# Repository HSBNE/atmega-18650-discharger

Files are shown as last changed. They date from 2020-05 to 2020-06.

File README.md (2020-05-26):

# atmega-18650-discharger

An arduino. atmega1280/2560 18650 battery discharger and capacity tester supporting 30 concurrent battery's being discharged, simple mobile phone interface using wifi, OSC protocol and UDP messages to off-the-shelf phone application called 'Touch OSC'. 

Discharges what is assumed ot be a fully-charged 18650 down till a given threshold, then stops the discharging, measuring the actual discharge profile over time and tells user the measure capacity at hte end of the discharge cycle.

Original code by @davidbuzz, working with esp8266/esp12 as wifi interface and master controller and 2x Arduino Mega 2560 slaves.

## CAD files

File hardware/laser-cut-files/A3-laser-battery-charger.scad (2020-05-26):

//page size
w=297;
h=420;

// battery "single" size ( in this case it's a pair ) 
batt_w = 18.5;
batt_h = 70;

// frame outer dimension
perimeter = 11;

// inner-spacing
wide_inner = 10;
thin_inner = 10;

// batteries in a stack = 20
battstack = 1;

// holeoffsets
holeoffset1 = 6;
holeoffset2 = 16;


//echo((h-(batt_h*battstack))/2);

difference(){ 
square([w,h],centre=false); // A3 sheet to start on.

// three rows out from centre.
for (i = [-140,-20,100]){ 

translate ( [0,i,0] ) {     
offset1 = perimeter;
translate([offset1,(h-(batt_h*battstack))/2,0]) square([batt_w,batt_h*battstack],centre=false);
translate([offset1+6,(h-(batt_h*battstack))/2-3,0]) square([6,1],centre=false);
translate([offset1+6,(h-(batt_h*battstack))/2-5,0]) square([6,1],centre=false);
translate([offset1+6,(h-(batt_h*battstack))/2+batt_h+3,0]) square([6,1],centre=false);
translate([offset1+6,(h-(batt_h*battstack))/2+batt_h+5,0]) square([6,1],centre=false);

offset2 = offset1+batt_w+wide_inner;
translate([offset2,(h-(batt_h*battstack))/2,0]) square([batt_w,batt_h*battstack],centre=false);
translate([offset2+6,(h-(batt_h*battstack))/2-3,0]) square([6,1],centre=false);
translate([offset2+6,(h-(batt_h*battstack))/2-5,0]) square([6,1],centre=false);
translate([offset2+6,(h-(batt_h*battstack))/2+batt_h+3,0]) square([6,1],centre=false);
translate([offset2+6,(h-(batt_h*battstack))/2+batt_h+5,0]) square([6,1],centre=false);
    
offset3 = offset2+batt_w+thin_inner;
translate([offset3,(h-(batt_h*battstack))/2,0]) square([batt_w,batt_h*battstack],centre=false);
translate([offset3+6,(h-(batt_h*battstack))/2-3,0]) square([6,1],centre=false);
translate([offset3+6,(h-(batt_h*battstack))/2-5,0]) square([6,1],centre=false);
translate([offset3+6,(h-(batt_h*battstack))/2+batt_h+3,0]) square([6,1],centre=false);
translate([offset3+6,(h-(batt_h*battstack))/2+batt_h+5,0]) square([6,1],centre=false);
    
offset4 = offset3+batt_w+wide_inner;
translate([offset4,(h-(batt_h*battstack))/2,0]) square([batt_w,batt_h*battstack],centre=false);
translate([offset4+6,(h-(batt_h*battstack))/2-3,0]) square([6,1],centre=false);
translate([offset4+6,(h-(batt_h*battstack))/2-5,0]) square([6,1],centre=false);
translate([offset4+6,(h-(batt_h*battstack))/2+batt_h+3,0]) square([6,1],centre=false);
translate([offset4+6,(h-(batt_h*battstack))/2+batt_h+5,0]) square([6,1],centre=false);
    
offset5 = offset4+batt_w+thin_inner;
translate([offset5,(h-(batt_h*battstack))/2,0]) square([batt_w,batt_h*battstack],centre=false);
translate([offset5+6,(h-(batt_h*battstack))/2-3,0]) square([6,1],centre=false);
translate([offset5+6,(h-(batt_h*battstack))/2-5,0]) square([6,1],centre=false);
translate([offset5+6,(h-(batt_h*battstack))/2+batt_h+3,0]) square([6,1],centre=false);
translate([offset5+6,(h-(batt_h*battstack))/2+batt_h+5,0]) square([6,1],centre=false);

offset6 = offset5+batt_w+wide_inner;
translate([offset6,(h-(batt_h*battstack))/2,0]) square([batt_w,batt_h*battstack],centre=false);
translate([offset6+6,(h-(batt_h*battstack))/2-3,0]) square([6,1],centre=false);
translate([offset6+6,(h-(batt_h*battstack))/2-5,0]) square([6,1],centre=false);
translate([offset6+6,(h-(batt_h*battstack))/2+batt_h+3,0]) square([6,1],centre=false);
translate([offset6+6,(h-(batt_h*battstack))/2+batt_h+5,0]) square([6,1],centre=false);

offset7 = offset6+batt_w+thin_inner;
translate([offset7,(h-(batt_h*battstack))/2,0]) square([batt_w,batt_h*battstack],centre=false);
translate([offset7+6,(h-(batt_h*battstack))/2-3,0]) square([6,1],centre=false);
translate([offset7+6,(h-(batt_h*battstack))/2-5,0]) square([6,1],centre=false);
translate([offset7+6,(h-(batt_h*battstack))/2+batt_h+3,0]) square([6,1],centre=false);
translate([offset7+6,(h-(batt_h*battstack))/2+batt_h+5,0]) square([6,1],centre=false);

offset8 = offset7+batt_w+wide_inner;
translate([offset8,(h-(batt_h*battstack))/2,0]) square([batt_w,batt_h*battstack],centre=false);
translate([offset8+6,(h-(batt_h*battstack))/2-3,0]) square([6,1],centre=false);
translate([offset8+6,(h-(batt_h*battstack))/2-5,0]) square([6,1],centre=false);
translate([offset8+6,(h-(batt_h*battstack))/2+batt_h+3,0]) square([6,1],centre=false);
translate([offset8+6,(h-(batt_h*battstack))/2+batt_h+5,0]) square([6,1],centre=false);

offset9 = offset8+batt_w+thin_inner;
translate([offset9,(h-(batt_h*battstack))/2,0]) square([batt_w,batt_h*battstack],centre=false);
translate([offset9+6,(h-(batt_h*battstack))/2-3,0]) square([6,1],centre=false);
translate([offset9+6,(h-(batt_h*battstack))/2-5,0]) square([6,1],centre=false);
translate([offset9+6,(h-(batt_h*battstack))/2+batt_h+3,0]) square([6,1],centre=false);
translate([offset9+6,(h-(batt_h*battstack))/2+batt_h+5,0]) square([6,1],centre=false);

offset10 = offset9+batt_w+thin_inner;
translate([offset10,(h-(batt_h*battstack))/2,0]) square([batt_w,batt_h*battstack],centre=false);
translate([offset10+6,(h-(batt_h*battstack))/2-3,0]) square([6,1],centre=false);
translate([offset10+6,(h-(batt_h*battstack))/2-5,0]) square([6,1],centre=false);
translate([offset10+6,(h-(batt_h*battstack))/2+batt_h+3,0]) square([6,1],centre=false);
translate([offset10+6,(h-(batt_h*battstack))/2+batt_h+5,0]) square([6,1],centre=false);

}

}



//bus holes
//translate([offset2-wide_inner/2,holeoffset1,0]) circle(d=6.5);
//translate([offset2-wide_inner/2,h-holeoffset1,0]) circle(d=6.5);
//translate([offset4-wide_inner/2,holeoffset1,0]) circle(d=6.5);
//translate([offset4-wide_inner/2,h-holeoffset1,0]) circle(d=6.5);
//translate([offset6-wide_inner/2,holeoffset1,0]) circle(d=6.5);
//translate([offset6-wide_inner/2,h-holeoffset1,0]) circle(d=6.5);

// mount holes
translate([w*1/32,holeoffset2,0]) circle(d=6.5);
translate([w*11/32,holeoffset2,0]) circle(d=6.5);
translate([w*21/32,holeoffset2,0]) circle(d=6.5);
translate([w*31/32,holeoffset2,0]) circle(d=6.5);

translate([w*1/32,h-holeoffset2,0]) circle(d=6.5);
translate([w*11/32,h-holeoffset2,0]) circle(d=6.5);
translate([w*21/32,h-holeoffset2,0]) circle(d=6.5);
translate([w*31/32,h-holeoffset2,0]) circle(d=6.5);

translate([w*1/32,140,0]) circle(d=6.5);
translate([w*11/32,140,0]) circle(d=6.5);
translate([w*21/32,140,0]) circle(d=6.5);
translate([w*31/32,140,0]) circle(d=6.5);

translate([w*1/32,260,0]) circle(d=6.5);
translate([w*11/32,260,0]) circle(d=6.5);
translate([w*21/32,260,0]) circle(d=6.5);
translate([w*31/32,260,0]) circle(d=6.5);

//optional ruler markes on cutouts. 
    
} 

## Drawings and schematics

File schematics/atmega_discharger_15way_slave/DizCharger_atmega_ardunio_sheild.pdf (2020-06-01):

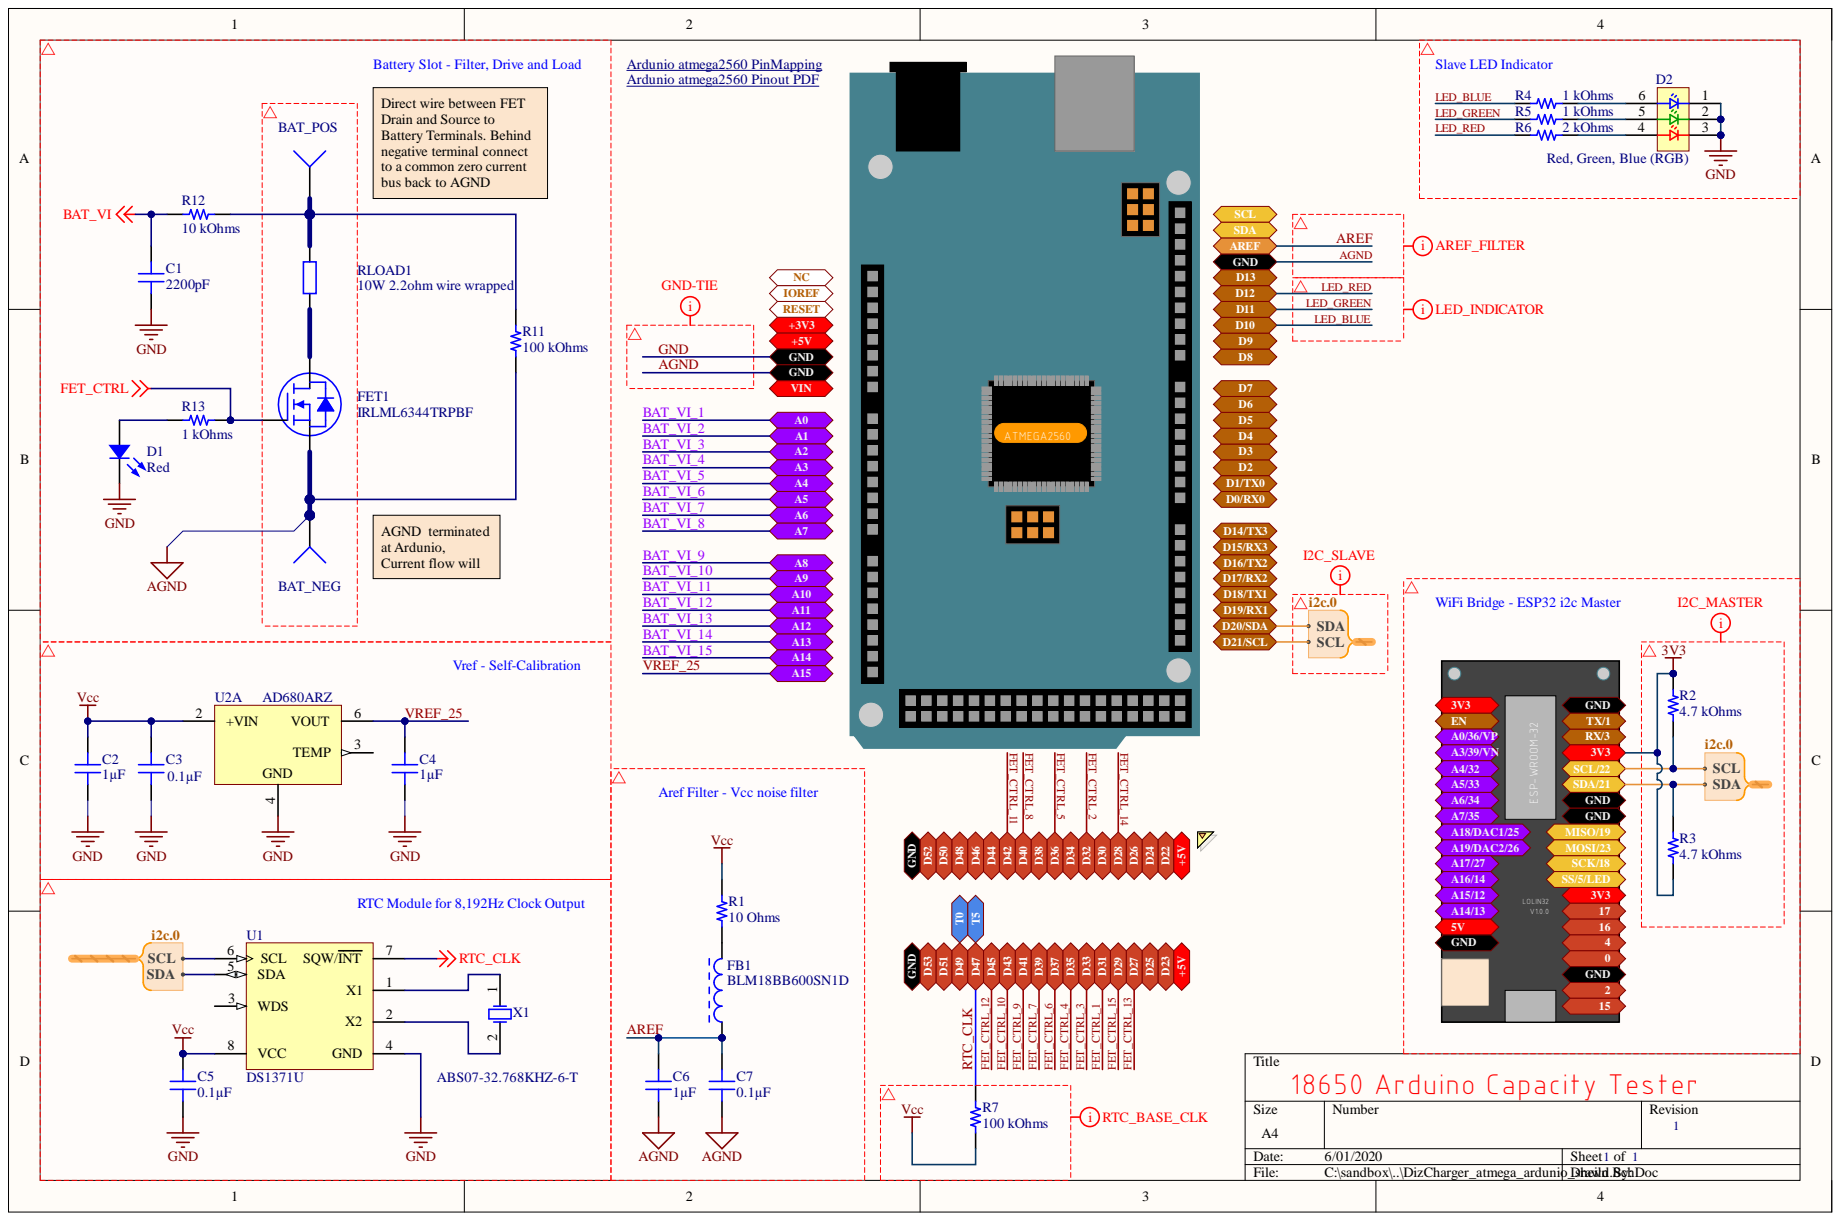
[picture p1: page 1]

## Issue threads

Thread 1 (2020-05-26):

Charge end-state-wait and state-discharge triggering incorrectly

ArakniD, 2020-05-26:
The end state should be maintained even when the voltage floats back upwards after a discharge. The discharge should not cycle again until voltage is removed entirely and float voltage goes above 4.130v

The start charge sequence should require a OCV above 4.130v before initiating a new discharge cycle.

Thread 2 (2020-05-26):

ADC Vref need a configuration #define for an external 4.5v Aref connection in place of A15 usage

ArakniD, 2020-05-26:
New configuration for the ADC using a 4.5v Aref connection instead of self-calibrating 2.5v on A15.

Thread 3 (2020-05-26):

WiFi Bridge needs an external switch to enable AP or Client mode

ArakniD, 2020-05-26:
Having an external switch allows taking the discharge mobile and in-field testing.

The WiFi AP mode needs to transmit data to ALL connected clients.

Implement the transmission of the multi-dial socket-loss from the esp32 code, mirror whats in node-red.

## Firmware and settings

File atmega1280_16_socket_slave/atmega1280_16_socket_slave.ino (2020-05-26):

// with I2C slave support!  see other sketch called esp8266_wifi_bridge.ino for master, with OSC etc. 
#include <Wire.h>

// 1 -> whatever
#define DEVICEID 2
// I2C device IDs start at 8 and go up.
#define I2C_DEVICEID DEVICEID+8

// earlier code had only 3 on Nano, etc.
#define POSITIONS 16

int DEBUG = 1;

// battery constant characteristics
float LiMinThreshold = 2700; //3900; //2700; // 2700 = Lithium Minimal Voltage for load removal, 3900 = minimum needed for re-charger to kick in.
float LiMaxThreshold = 4220; // Lithium Max Voltage for load removal
int power_resistor_value = 2.2; // needs to be in the range 1.8-2.5 ohms. best is 2 or 2.2 ohms, typically approx 10W  ( eg, 2x1ohm 5w in series will do , or a 2.2ohm 10W) 

// 5V NANO ADC to mV VOLTAGE FACTOR is 4.887
// 5V MEGA1280 ADC to mV VOLTAGE FACTOR is 13.53
#define ADC 4.887
//#define ADC 130.1

int i;

//16 way! - the most important thing is 16 available ADCs, and 16 digital IO for mosfets, as a bonus, we have 16 digital io for LEDs too. and still spares after that. :
// constants
unsigned int sensor1Pins[POSITIONS] = { A0,A1,A2,A3,A4,A5,A6,A7,A8,A9,A10,A11,A12,A13,A14,A15 };
//int sensor2Pins[] = { 0, 4, 5 }; // we don't have 3 separate analog pins avail here because we use I2C on A4 and A5.
unsigned int ledPins[POSITIONS] = { 22,23,24,25,26,27,28,29,30,31,32,33,34,35,36,37 };
unsigned int FETPins[POSITIONS] = { 4,5,6,7,8,9,10,11,12,13,14,15,16,17,18,19 };  // don't use 20 or 21 for IO, as they are for I2C comms on a 2560.
unsigned int SPKPins[POSITIONS] = {  3, 3 , 3,3,3,3,3,3,3,3,3,3,3,3,3,3 };
// variables
unsigned int sensor1Values[POSITIONS] = { 0 , 0 ,0 ,0 ,0 ,0 ,0 ,0 ,0 ,0 ,0 ,0 ,0 ,0 ,0 , 0 };
//int sensor2Values[] = { 0 , 0 , 0 };
unsigned int BatVoltages[POSITIONS] = { 5000, 5000,5000,5000,5000,5000,5000,5000,5000,5000,5000,5000,5000,5000,5000, 5000};
unsigned int FetVoltages[POSITIONS] = { 40,40,40,40,40,40,40,40,40,40,40,40,40,40,40, 40}; // with enough spare ADCs we can calculate these, but for now we know its close to 40mV most of the time
unsigned int MilliAmps[POSITIONS] = { 0, 0,0,0,0,0,0,0,0,0,0,0,0,0,0, 0};    // these ints are 16bit values
unsigned long TotalCurrents[POSITIONS] = { 0, 0, 0, 0, 0, 0, 0, 0, 0, 0, 0, 0, 0, 0, 0, 0};   // LONG, as we go over 65k

boolean batterypresents[POSITIONS] = { false, false,false,false,false,false,false,false,false,false,false,false,false,false,false, false};
boolean dones[POSITIONS] =           { false, false,false,false,false,false,false,false,false,false,false,false,false,false,false, false} ;
boolean ledstates[POSITIONS] =       { false, false,false,false,false,false,false,false,false,false,false,false,false,false,false, false} ;
unsigned long PrevMilliss[POSITIONS]  =      {0,0,0,0,0,0,0,0,0,0,0,0,0,0,0,0};
unsigned long MillisPasseds[POSITIONS] =     {0,0,0,0,0,0,0,0,0,0,0,0,0,0,0,0};
unsigned long time_since_starts[POSITIONS] = {0,0,0,0,0,0,0,0,0,0,0,0,0,0,0,0}; 
unsigned long time_ends[POSITIONS] =         {0,0,0,0,0,0,0,0,0,0,0,0,0,0,0,0}; 

// I2C packet...... 
typedef struct sensorData_t{
  byte stx;
  byte DeviceID;   // device ID.   
  byte batvoltage1_low;
  byte batvoltage1_hi;
  byte Running1;
  byte MilliAmps1_low;
  byte MilliAmps1_hi;
  byte TotalCurrents1_low;
  byte TotalCurrents1_hi;
  byte time_ends1_low;
  byte time_ends1_hi;
  byte etx;
};
#define PACKET_SIZE 12  // can NEVER exceeed 32, hardware limit.
//#define PACKET_SIZE sizeof(sensorData_t)

// as bytes.....
typedef union I2C_Packet_t{
sensorData_t sensor;
byte I2CPacket[sizeof(sensorData_t)];
};
I2C_Packet_t batteryinfo;


void shortbeep(int pos){
            digitalWrite(SPKPins[pos], HIGH);
            delay(1);
            digitalWrite(SPKPins[pos], LOW);
}

byte REQUESTEDPOS = 0x00;
void receiveEvent(int bytes)
{
  if(Wire.available() != 0)
  {
    for(int i = 0; i< bytes; i++)
    {
      REQUESTEDPOS = Wire.read();
      if (DEBUG > 0 ) Serial.print("Received: ");
      if (DEBUG > 0 ) Serial.print(REQUESTEDPOS, HEX);
      if (DEBUG > 0 ) Serial.print("\n");
    }
  }
}

// just like analogRead only it does 2 slow reads and makes sure they are within 10% of each other
int debouncedAnalogRead(int pin){ 
  int trydata[] = { 0,100 } ;
  //for(int _try = 0; _try < 2 ; _try++ ) { 
      trydata[0] = analogRead(pin);
   //delay(50);
      trydata[1] = analogRead(pin);
   //delay(50);
  //}
  // ADC values are out of 1024, so 10% is about 100
  while (abs(trydata[0]-trydata[1]) > 10 ) {
    //Serial.println("poor ADC value");
    //Serial.println(abs(trydata[0]-trydata[1]));
   delay(50);

      trydata[0] = analogRead(pin);
   //delay(50);
      trydata[1] = analogRead(pin);
   //delay(50);
    
//    Serial.println
  }
  return trydata[1]; // second try is probably better. 
}

// function that executes whenever data is requested by master
// this function is registered as an event, see setup()
void requestEvent() {

    if ((REQUESTEDPOS < 0) or ( REQUESTEDPOS > POSITIONS )) { REQUESTEDPOS = 0; } // if not given a decent offset, assume the first one.

    // turn human readable 1-based offset back to 0-based array offset:
    int __REQUESTEDPOS = REQUESTEDPOS-1;

    // fill the packet 
    batteryinfo.sensor.stx=2; // just becasue, we don't use this other than to tel that a packet is not all zeros
    batteryinfo.sensor.DeviceID=DEVICEID; // human-readable of DeviceID is passed back too.
    batteryinfo.sensor.batvoltage1_low = (byte)BatVoltages[__REQUESTEDPOS];
    batteryinfo.sensor.batvoltage1_hi = BatVoltages[__REQUESTEDPOS]  >> 8;
    batteryinfo.sensor.Running1= dones[__REQUESTEDPOS]?0:1;
    batteryinfo.sensor.MilliAmps1_low = (byte)MilliAmps[__REQUESTEDPOS];
    batteryinfo.sensor.MilliAmps1_hi = MilliAmps[__REQUESTEDPOS]  >> 8;
    batteryinfo.sensor.TotalCurrents1_low = (byte)(TotalCurrents[__REQUESTEDPOS]/1000);
    batteryinfo.sensor.TotalCurrents1_hi = (TotalCurrents[__REQUESTEDPOS]/1000)  >> 8;
    batteryinfo.sensor.time_ends1_low = (byte)time_ends[__REQUESTEDPOS];
    batteryinfo.sensor.time_ends1_hi = time_ends[__REQUESTEDPOS]  >> 8;
    batteryinfo.sensor.etx=REQUESTEDPOS; // pass back the human-readable of REQUESTEDPOS

    // send the packet.
    Wire.write(batteryinfo.I2CPacket, PACKET_SIZE);

  
}

void cycle_leds(){
  Serial.println("Cycling LEDs");

   for( int pos = 0 ; pos < POSITIONS ; pos++ ) { 
     digitalWrite(ledPins[pos], HIGH);   // turn the LED on (HIGH is the voltage level)
      delay(200);              // wait for a second
      digitalWrite(ledPins[pos], LOW);    // turn the LED off by making the voltage LOW
      delay(200);              // wait for a second
   }
  Serial.println("LEDs test done");
}

void setup() {
  
  Serial.begin(57600);// start serial port to send data during run to the PC
  Serial.println("Bat PWR Tester[Active]");  // Print a message to the //lcd.
  Serial.println("Detecting Bat .... please put one in now if not already...."); // print voltage value
  Serial.println("                        ");
  Serial.println(PACKET_SIZE);

  // init all the IO and pullups and lEDs etc. 
  for( int pos = 0 ; pos < POSITIONS ; pos++ ) { 
    
      pinMode(ledPins[pos], OUTPUT);//activation led and enable for FET
      pinMode(FETPins[pos], OUTPUT);//activation led and enable for FET
      pinMode(SPKPins[pos], OUTPUT);//activation led and enable for FET
   
      //elay(200);  //s[pos]
      digitalWrite(ledPins[pos], HIGH);   // set the LED on
      digitalWrite(FETPins[pos], HIGH);   // set the LED on
      digitalWrite(ledPins[pos], LOW);   // set the LED off
      digitalWrite(FETPins[pos], LOW);   // set the LED off

      // read ADC
      sensor1Values[pos] = debouncedAnalogRead(sensor1Pins[pos]);   // read the value from the sensor:
  
      // Detecting battery type
      BatVoltages[pos] = sensor1Values[pos]*ADC;
      
      Serial.print("\tDevice=");

      Serial.print(sensor1Values[pos]); // raw ADC 
      Serial.print("\t");
      
      Serial.print(pos+1); // print displayable position, starting from .1
      Serial.print("\t");
                 
      if (BatVoltages[pos] > LiMaxThreshold){
        Serial.print("Warning high-V! V > 4.5 \t");
        dones[pos] = true;
        batterypresents[pos] = true;
      }
    
      if (BatVoltages[pos] > LiMinThreshold){
        Serial.print("Type:Li-Ion Bat. \t");
        batterypresents[pos] = true;
       }
    
      if (BatVoltages[pos] < 2){
        Serial.print("Unknown or FLAT BATTERY V<2 \t");
        dones[pos] = true;
        batterypresents[pos] = false;
      }
      
      Serial.print("\tV=");
      Serial.print(sensor1Values[pos]*ADC); // print voltage value
      Serial.println("mV");

  PrevMilliss[pos]  = millis();
  time_since_starts[pos] = millis();

  } 

  cycle_leds(); // demo/tester

  // after all the GPIOs are init-ed to their correct state, we can start listening for wire transfers.   
  Wire.begin(I2C_DEVICEID);     // join i2c bus with an address above #8
  Wire.onReceive(receiveEvent); // for incoming data TO slave 
  Wire.onRequest(requestEvent); // register event to trigger outgoing data FROM slave


  //delay(1000);
  Serial.println("-------------------------------------------------------------");
  
  shortbeep(0);
}


void loop() {
      Serial.println("-------------------------------------------------------------");
            delay(1000);

    for( int pos = 0 ; pos < POSITIONS ; pos++ ) { 
  
          if (BatVoltages[pos] > LiMinThreshold && !dones[pos]) {
            digitalWrite(ledPins[pos], HIGH);   // set the LED on
            digitalWrite(FETPins[pos], HIGH);   // set the LED on
            sensor1Values[pos] = debouncedAnalogRead(sensor1Pins[pos]);   // read the value from the sensor:
            BatVoltages[pos] = (sensor1Values[pos]*ADC);
            //sensor2Values[pos] = analogRead(sensor2Pins[pos]);   // read the value from the FET:
            //FetVoltages[pos] = (sensor2Values[pos]*ADC);  // this is the way to calculate it if you don't use the default value

            Serial.print("\tDevice=");
            Serial.print(DEVICEID); // print voltage value
            Serial.print(".");
            Serial.print(pos+1); // print human readable starting from 1
            
 
            Serial.print("\t[RUNNING] BattmV=");
            Serial.print(BatVoltages[pos]); // print voltage value
            
   
            MilliAmps[pos] = (BatVoltages[pos]-FetVoltages[pos])/power_resistor_value; 
            if ( MilliAmps[pos] < 0 ) { MilliAmps[pos] = 0; } // dissallow neg values
            if ( MilliAmps[pos] > 32000 ) { MilliAmps[pos] = 0; } // dissallow neg values
            Serial.print("\tmilliAmps=");
            Serial.print(MilliAmps[pos]); // print value        
            
            TotalCurrents[pos]=TotalCurrents[pos]+MillisPasseds[pos]/1000*MilliAmps[pos]/3.6; 
            Serial.print("  \tI=");
            Serial.print(TotalCurrents[pos]/1000);
            Serial.print("mAH  ");

            MillisPasseds[pos] = millis()- PrevMilliss[pos] ;
            PrevMilliss[pos] = millis();
    
            Serial.print("\tSecs:");    // prints a tab
            time_ends[pos] = int((millis()-time_since_starts[pos])/1000);
            Serial.print(time_ends[pos]);
 
            Serial.print("\t FETmV=");
            Serial.print(FetVoltages[pos]); // print value
 
            Serial.println();
          }
          else
          {
            // if we've "finished" ( moving to the done state ) , beep once.
            if (dones[pos] == false ) {
              shortbeep(pos);
              //time_ends[pos] = int((millis()-time_since_starts[pos])/1000);
            }
            dones[pos]=true;

            
            digitalWrite(ledPins[pos], LOW);   // set the LED off - stop loading
            digitalWrite(FETPins[pos], LOW);   // set the LED off - stop loading

            Serial.print("\tDevice=");
            Serial.print(DEVICEID); // print voltage value
            Serial.print(".");
            Serial.print(pos+1); // print voltage value
            Serial.print("\t[ DONE  ] ");  // Print a message to the //lcd.
    
            sensor1Values[pos] = debouncedAnalogRead(sensor1Pins[pos]);   // read the value from the sensor:
            BatVoltages[pos] = (sensor1Values[pos]*ADC);
    
            Serial.print("BattmV=");
            Serial.print(BatVoltages[pos]); // print voltage value

            Serial.print("\tmilliAmps=");
            Serial.print(MilliAmps[pos]); // print value        
 
            Serial.print("  \tI=");
            Serial.print(TotalCurrents[pos]/1000);    
            Serial.print("mAH  ");

            Serial.print("\tSecs:");    // prints a tab
            Serial.print(time_ends[pos]);

  
            // if battery is still in holder, but we are done with it... flash LED of appropriate slot..
            if ( batterypresents[pos] ) { 
                  if ( ledstates[pos] == LOW ) { 
                      digitalWrite(ledPins[pos], HIGH);
                      ledstates[pos] = HIGH;
                  } else { 
                      digitalWrite(ledPins[pos], LOW);
                      ledstates[pos] = LOW; 
                  }
                  //delay(100);
            } 

            bool restarting = false;
            
            // if the battery voltage is suddenly LOWER than 1v, it was clearly taken OUT. 
            if (( batterypresents[pos] == true) and (BatVoltages[pos] < 1000 )  ) { 
              batterypresents[pos]  = false;
              restarting = true;
              Serial.print("\tLOWER ");
            }
            // if the battery voltage is suddenly HIGHER than 1v when it wasn't before, we've clearly put a battery IN.
            if ( ( batterypresents[pos] == false) and ( BatVoltages[pos] > 1000 ) ) { 
              batterypresents[pos] = true; 
              restarting = true;
              Serial.print("\tHIGHER ");

            }

            // we restart based on HIGH or LOW voltage change....
            if (restarting == true ) { 
                Serial.print("\tDetected ADD/REMOVE .. restarting! "); 
                TotalCurrents[pos] = 0;
                dones[pos] = false;   
                time_since_starts[pos] = millis();
                shortbeep(pos);  // if we've "started" ( moving to the discharging state ) , beep once.
                time_ends[pos] = 0;
            }
            Serial.println();
          }
    }
}

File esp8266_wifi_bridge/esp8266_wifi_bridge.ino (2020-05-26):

// we install this library and then dont use it: https://github.com/tzapu/WiFiManager
// very helpful: see also http://www.elinistech.com/images/esp8266/The-ESP8266-Book-September-2015.pdf
// and comments at : https://github.com/esp8266/Arduino/issues/471
// and https://github.com/sandeepmistry/esp8266-OSC/blob/master/examples/UDPSendBundle/UDPSendBundle.ino
// NOTE:   code tested using arduino IDE 1.6.7 AND esp8266 board plugin version 2.0.0  ( which is def not the latest, but will do ) 

//CODE WORKS IN CONJUNCTION WITH _18650_discharger_three_way programmed into upto 10x Arduino Nanos used for smart-discharger/s


#include <ESP8266WiFi.h>

#include <OSCMessage.h>
#include <OSCBundle.h>

#include <DNSServer.h>            //Local DNS Server used for redirecting all requests to the configuration portal
//#include <ESP8266WebServer.h>     //Local WebServer used to serve the configuration portal
#include <WiFiManager.h>          //https://github.com/tzapu/WiFiManager WiFi Configuration Magic
#include <WiFiUdp.h>


int DEBUG = 3; // 0 = less, 1 or higher = more

// BUZZ MASTER I2C on ESP8266  - WILL NOT COMPILE FOR AVR as-is, make sure your target is an esp8266 board.


#include <Wire.h>
#define I2CAddressESPWifi 8


// I2C packet...... 
typedef struct sensorData_t{
  byte stx;
  byte DeviceID;   // device ID.   
  byte batvoltage1_low;
  byte batvoltage1_hi;
  byte Running1;
  byte MilliAmps1_low;
  byte MilliAmps1_hi;
  byte TotalCurrents1_low;
  byte TotalCurrents1_hi;
  byte time_ends1_low;
  byte time_ends1_hi;
  byte etx;
};
#define PACKET_SIZE 12
//#define PACKET_SIZE sizeof(sensorData_t)

// as bytes.....
typedef union I2C_Packet_t{
sensorData_t sensor;
byte I2CPacket[sizeof(sensorData_t)];
};
// a single incoming packet....
I2C_Packet_t batteryinfo;


  //the message wants an OSC address as first argument
  //OSCMessage msg("/analog/0");
  //msg.add((int32_t)analogRead(0));

int NeedRefresh = 0;

extern "C" {
  #include "user_interface.h"
//  #include "ip_addr.h"
//  #include "mem.h"

  // callback context should NOT have blocking ( Serial.println ) calls. bad. 
  void _onWiFiEvent(System_Event_t *event){
    NeedRefresh = 1;
    if(event->event == EVENT_SOFTAPMODE_STACONNECTED){
      Event_SoftAPMode_StaConnected_t *data = (Event_SoftAPMode_StaConnected_t *)(&event->event_info.sta_connected);
      //Serial.printf("Station Connected: id: %d, mac: " MACSTR "\n", data->aid, MAC2STR(data->mac));
    } else if(event->event == EVENT_SOFTAPMODE_STADISCONNECTED){
      Event_SoftAPMode_StaDisconnected_t *data = (Event_SoftAPMode_StaDisconnected_t *)(&event->event_info.sta_disconnected);
      //Serial.printf("Station Disconnected: id: %d, mac: " MACSTR "\n", data->aid, MAC2STR(data->mac));
    }
  }
}
// the connected CLIENT IP address/s, if any. ( populated by count_stations), and 
// the target for where all teh UDP OSC messages go. 
IPAddress clientips[4];

//const IPAddress outIp(192,168,192,28);        // remote IP of your computer
const unsigned int outPort = 9000;          // remote port to receive OSC
const unsigned int localPort = 8888;        // local port to listen for OSC packets (actually not used for sending)

WiFiUDP udp;


// count devices that have fully DHCPd and have IP adresses:
int count_stations(){
    struct station_info *stat_info;
    struct ip_addr *ipaddr;
    //IPAddress ip; see clientips
    int retries = 0;
    int count = 0;
    stat_info = NULL;
        
    // get a non-null stat_info
    while ((stat_info == NULL) and ( retries < 10)) {  // wait for the dhcp to finish and get an actual IP.
      if (DEBUG >0 ) Serial.print("X");
      stat_info = wifi_softap_get_station_info();
      delay(500);
      retries++;
    }
    // iterate over the stat_info to see how many we have..? 
    while (stat_info != NULL) {
      ipaddr = &stat_info->ip;
      clientips[count] = ipaddr->addr;
      //ip=ipaddr->addr;
      if (DEBUG >0 ) Serial.println(clientips[count].toString());
      stat_info = STAILQ_NEXT(stat_info, next);
      count++;
    }
    int zerofill = 0;
    zerofill = count;
    while(zerofill < 4){
      clientips[count][0] = 0; // 4 octets of an IP.
      clientips[count][1] = 0;
      clientips[count][2] = 0;
      clientips[count][3] = 0;
      zerofill++;
    }
    //Serial.printf("count: %d\n",count);
    return count;
}

/* 
 *  this works, but it relies on the wifi_softap_get_station_num() function which returns BEFORE dhcp has issues IPs to all connected.
// this should only be called "moments" after a System_Event_t wifi connect or disconnect event has occurrred on the AP.
// and it does not wait for long...
void _oldwait_for_new_connection(){
  static unsigned int last_time_we_were_called_we_had_how_many_devices = 0;  // safe to assume zero clients on startup, but not at any other time.  :-) 
  unsigned int softap_stations_cnt = 255;
  int retries = 0;
  Serial.printf("was clients: %d   \n", last_time_we_were_called_we_had_how_many_devices);

  //  retries limit
  softap_stations_cnt = wifi_softap_get_station_num();
  while ((softap_stations_cnt == last_time_we_were_called_we_had_how_many_devices) and (retries < 5)) { // this maxes out at around 5 seconds
    softap_stations_cnt = wifi_softap_get_station_num();
    retries++;
    delay(1000);
    //Serial.printf("retries: %d %d\n",retries,softap_stations_cnt);
    Serial.print(".");
  }
  last_time_we_were_called_we_had_how_many_devices = softap_stations_cnt; // new count
  Serial.printf("now clients: %d    \n", last_time_we_were_called_we_had_how_many_devices);
}
*/

// this should only be called "moments" after a System_Event_t wifi connect or disconnect event has occurrred on the AP.
// and it does not wait for long...
void wait_for_new_connection(){
  static unsigned int last_time_we_were_called_we_had_how_many_devices = 0;  // safe to assume zero clients on startup, but not at any other time.  :-) 
  unsigned int softap_stations_cnt = 255;
  int retries = 0;
  if (DEBUG >0 ) Serial.printf("conencted clients: %d   \n", last_time_we_were_called_we_had_how_many_devices);

  // retries limit .. 
  softap_stations_cnt = count_stations();
  while ((softap_stations_cnt == last_time_we_were_called_we_had_how_many_devices) and (retries < 5)) { // this maxes out at around 5 seconds ( 100x100ms)
    softap_stations_cnt = count_stations();
    retries++;
    delay(1000);
    //Serial.printf("retries: %d %d\n",retries,softap_stations_cnt);
    if (DEBUG >0 ) Serial.print(".");
  }
  last_time_we_were_called_we_had_how_many_devices = softap_stations_cnt; // new count
  if (DEBUG >0 ) Serial.printf("conencted clients: %d    \n", last_time_we_were_called_we_had_how_many_devices);
}
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

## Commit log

2020-05-25 Initial modified working version
    *Self-calibrating Vcc Vref via A15 2.5v reference
    *Pulsed current to measure cell voltage without mV drop from leaf sprung sockets
    *External RTC (8,192Hz) clock to sync both atmega and integrate from better time-base than CPU_CLOCK
    *Node-red + Influx DB web-ui with barcode scanner for tracing battery results and curves (done, needs isolation to check in)
    *ESP32 WiFi Client/AP with Android App for socket adjustments and seeing live results
2020-05-26 Original code by Buzz.
    [atmega1280_16_socket_slave.ino, esp8266_wifi_bridge.ino]
2020-05-26 Heavily expanded version by @ArakniD, using esp32 , node-red , barcodes, etc.
    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
2020-05-26 added buzzs original file/s for laser-cut, based on .scad file
    [A3-laser-battery-charger.scad]
2020-06-01 Initial Ardunio sheild connections for current code
    Ardunio Sheild connection
    Per slot drivers and indicators
    Master WiFi bridge connection
    [DizCharger_atmega_ardunio_sheild.SchDoc, atmega_discharger_15way_slave.PrjPcb]
2020-06-05 Adding node-red flow
    May require manual IP address fix ups
    Used with hassio and configured influxDB
2020-06-05 Adding base project
    New ideas
    [2020-06-01_06-32-02.PcbLib, 2020-06-01_06-32-02.SchLib, Arak-18650-Holder.SchDoc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]
